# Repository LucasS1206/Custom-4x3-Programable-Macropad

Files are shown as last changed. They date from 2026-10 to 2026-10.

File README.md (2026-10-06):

# Custom 4x3 Macropad (with Rotary Encoder & OLED)
A custom 4x3 mechanical macropad I designed and built from scratch. This was designed for the intention of a dedicated keypad for a daily computer setup. I used this project as an opportunity to walk through the entire hardware development process from designing the circuit board in KiCad to writing the embedded C firmware in QMK.

## System Features
Layout: A 4x3 grid (12 keys) for custom shortcuts and macros.

Rotary Encoder: An EC11 clickable dial for master volume and media control.

Display: A 1.3" SH1106 OLED screen for real-time visual feedback.

Microcontroller: Pro Micro RP2040.

Firmware: Custom QMK integration, giving me complete control over every key switch, screen display, and dial action.

## Hardware Design (KiCad)
The hardware architecture and PCB were developed using KiCad 10.0:

Schematics: Built a 4x3 switch matrix with diodes to prevent key ghosting, alongside the specific pin routing for the encoder and microcontroller.

PCB Layout: Routed a compact, custom circuit board.

Iterative Design: During the layout phase, I caught and fixed an orientation error with the microcontroller footprint and adjusted the top-layer copper pour clearances to make sure the board would manufacture correctly without short-circuiting.

## QMK Firmware
The /firmware directory contains the configuration files (keymap.c, keyboard.json, config.h, and rules.mk) required to run the system.

## Repository Structure
/Hardware: The primary KiCad 10.0 design files (.kicad_pro, .kicad_sch, .kicad_pcb).

/firmware/testpad: The custom QMK configuration source files.

/Images: System documentation through images of all parts of the design proccess.

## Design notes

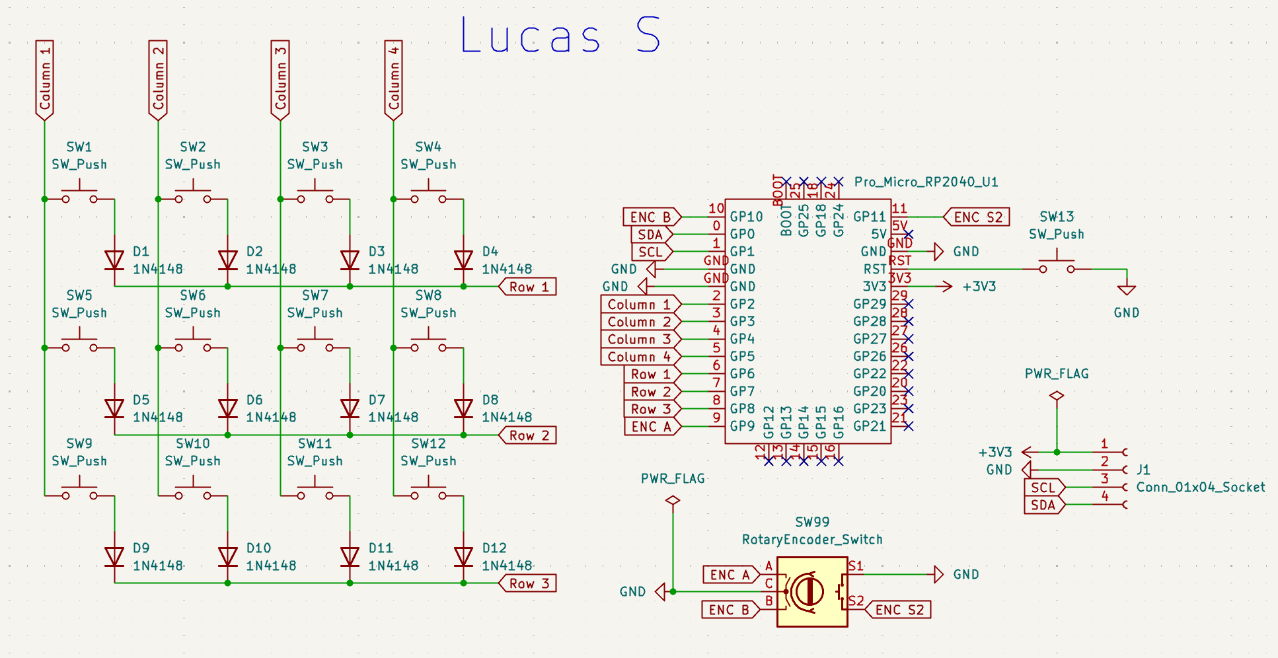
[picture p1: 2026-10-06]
Images/Schematic.png

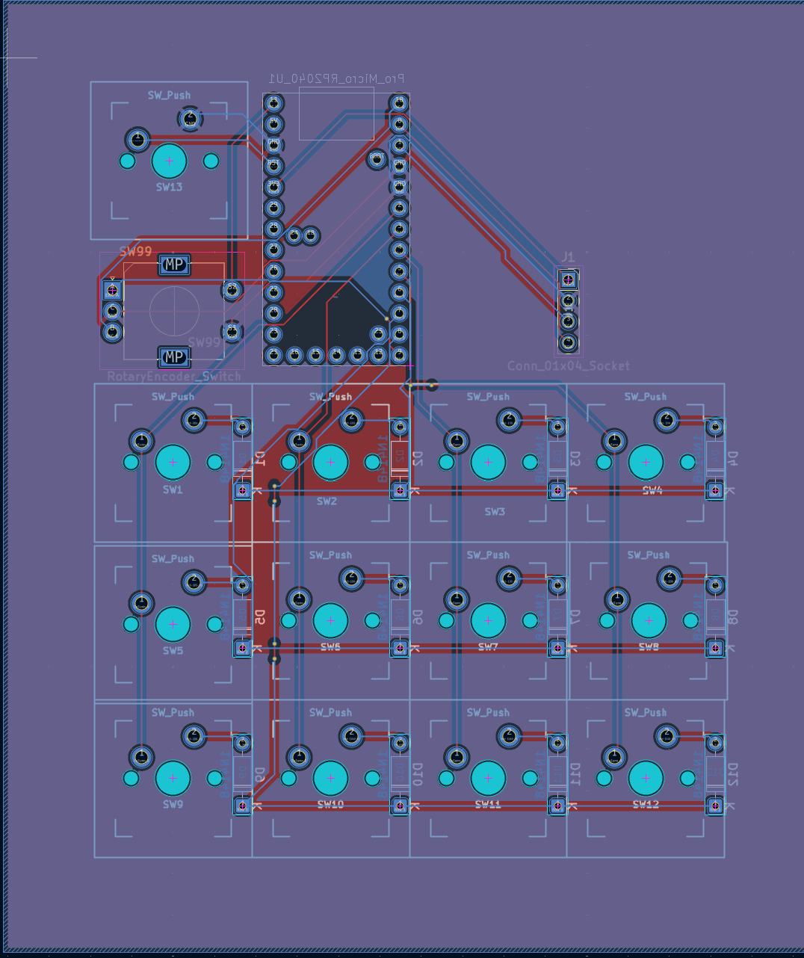
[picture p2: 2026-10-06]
Images/PCB Layout.png

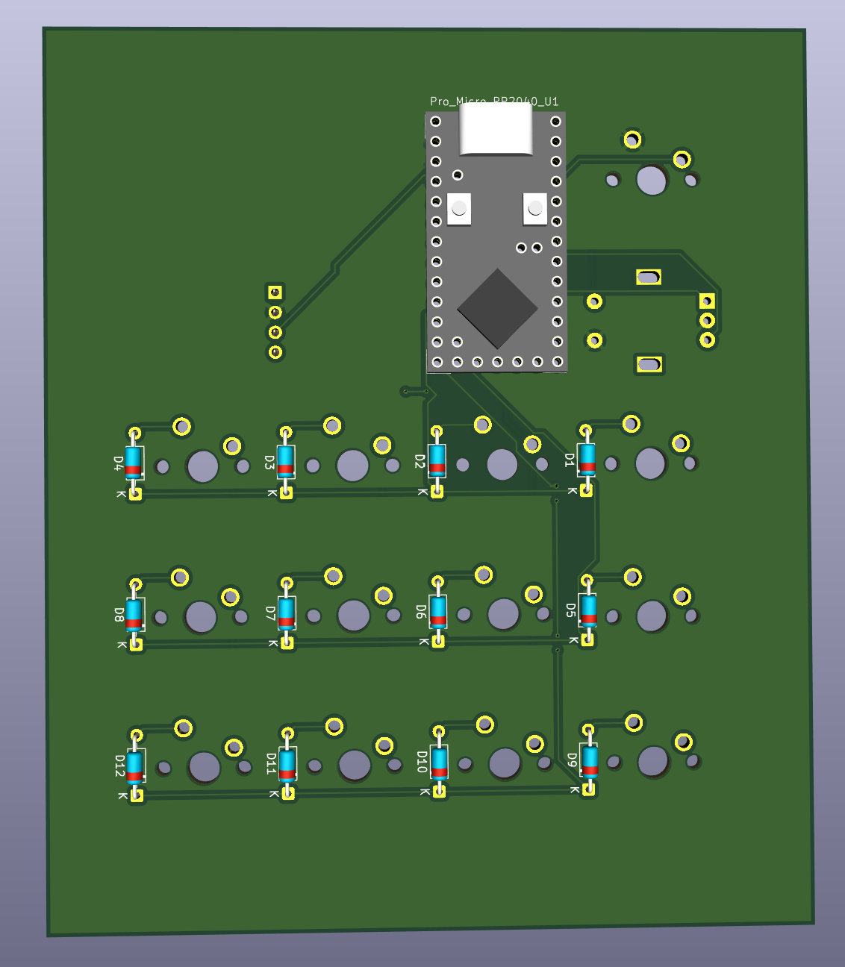
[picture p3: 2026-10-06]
Images/PCB 3D Model (Back).png

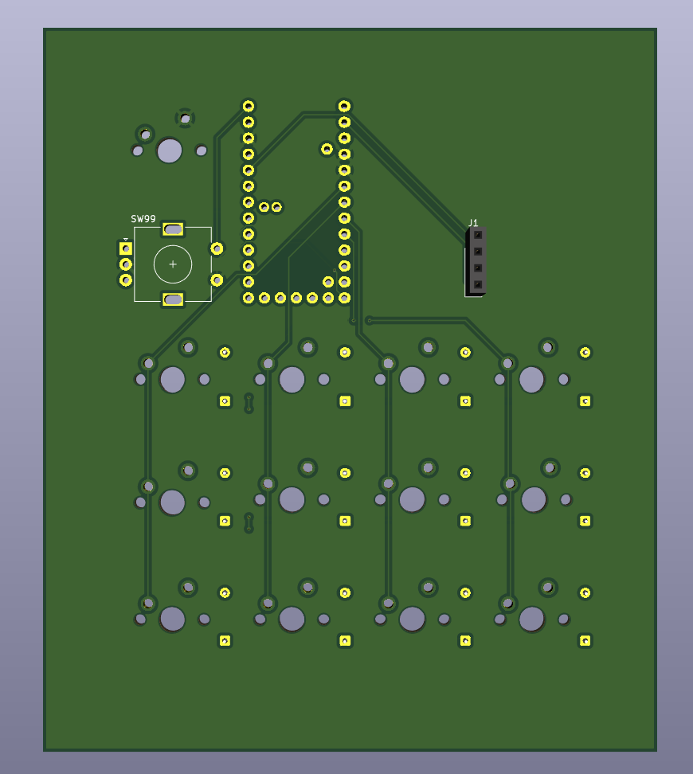
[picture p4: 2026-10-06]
Images/PCB 3D Model (Front).png

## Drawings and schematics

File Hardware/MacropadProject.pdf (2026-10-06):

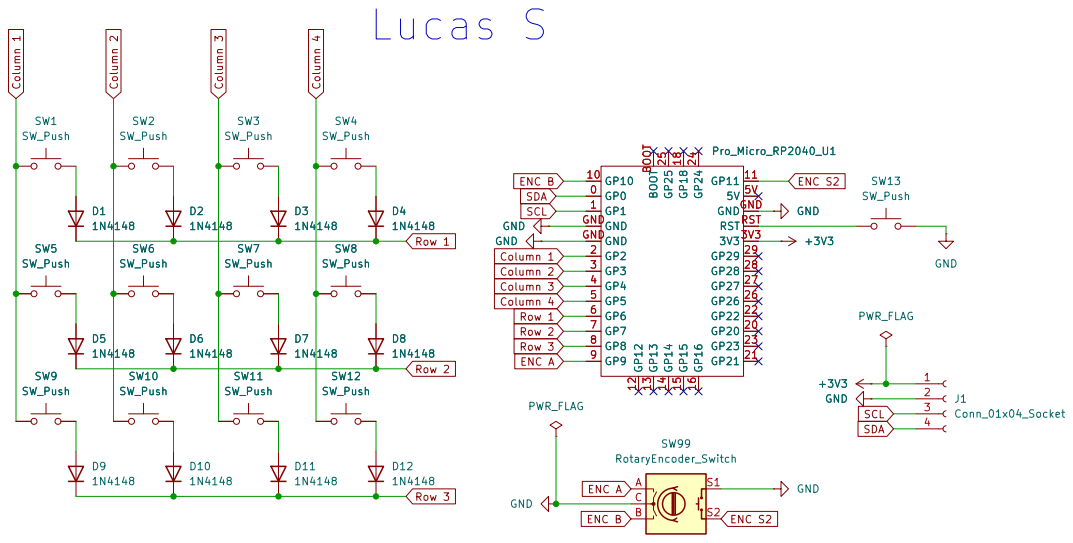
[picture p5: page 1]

SCL SDA Column 4 Column 2 Column 1 Row 1 Lucas S

Size: A4 | Rev:
KiCad E.D.A. 10.0.5 | Id: 1/1

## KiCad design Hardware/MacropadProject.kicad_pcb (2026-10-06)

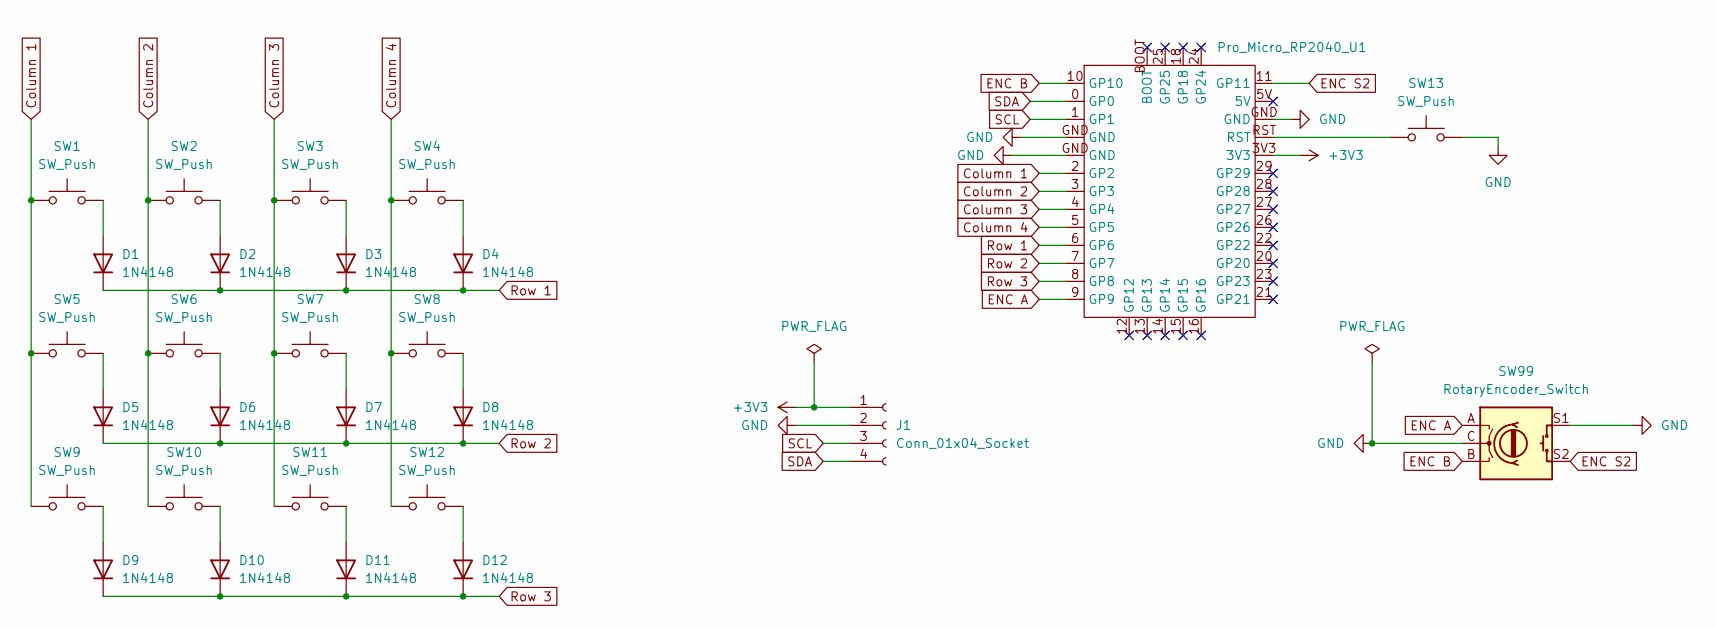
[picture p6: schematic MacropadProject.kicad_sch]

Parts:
D1, D2, D3, D4, D5, D6, D7, D8, D9, D10, D11, D12: 1N4148; D_DO-35_SOD27_P7.62mm_Horizontal
J1: Conn_01x04_Socket; PinSocket_1x04_P2.54mm_Vertical
Pro_Micro_RP2040_U1: pro_micro_rp2040
SW1, SW2, SW3, SW4, SW5, SW6, SW7, SW8, SW9, SW10, SW11, SW12, SW13: SW_Push; MX-Solderable-1U
SW99: RotaryEncoder_Switch; RotaryEncoder_Alps_EC11E-Switch_Vertical_H20mm

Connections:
+3V3: J1.1, Pro_Micro_RP2040_U1.3V3
Column 1: Pro_Micro_RP2040_U1.2 (GP2), SW1.1, SW5.1, SW9.1
Column 2: Pro_Micro_RP2040_U1.3 (GP3), SW2.1, SW6.1, SW10.1
Column 3: Pro_Micro_RP2040_U1.4 (GP4), SW3.1, SW7.1, SW11.1
Column 4: Pro_Micro_RP2040_U1.5 (GP5), SW4.1, SW8.1, SW12.1
ENC A: Pro_Micro_RP2040_U1.9 (GP9), SW99.A
ENC B: Pro_Micro_RP2040_U1.10 (GP10), SW99.B
ENC S2: Pro_Micro_RP2040_U1.11 (GP11), SW99.S2
GND: J1.2, Pro_Micro_RP2040_U1.GND, SW13.2, SW99.C, SW99.S1
unnamed: D1.2 (A), SW1.2
unnamed: D2.2 (A), SW2.2
unnamed: D3.2 (A), SW3.2
unnamed: D4.2 (A), SW4.2
unnamed: D5.2 (A), SW5.2
unnamed: D6.2 (A), SW6.2
unnamed: D7.2 (A), SW7.2
unnamed: D8.2 (A), SW8.2
unnamed: D9.2 (A), SW9.2
unnamed: D10.2 (A), SW10.2
unnamed: D11.2 (A), SW11.2
unnamed: D12.2 (A), SW12.2
unnamed: Pro_Micro_RP2040_U1.RST, SW13.1
Row 1: D1.1 (K), D2.1 (K), D3.1 (K), D4.1 (K), Pro_Micro_RP2040_U1.6 (GP6)
Row 2: D5.1 (K), D6.1 (K), D7.1 (K), D8.1 (K), Pro_Micro_RP2040_U1.7 (GP7)
Row 3: D9.1 (K), D10.1 (K), D11.1 (K), D12.1 (K), Pro_Micro_RP2040_U1.8 (GP8)
SCL: J1.3, Pro_Micro_RP2040_U1.1 (GP1)
SDA: J1.4, Pro_Micro_RP2040_U1.0 (GP0)

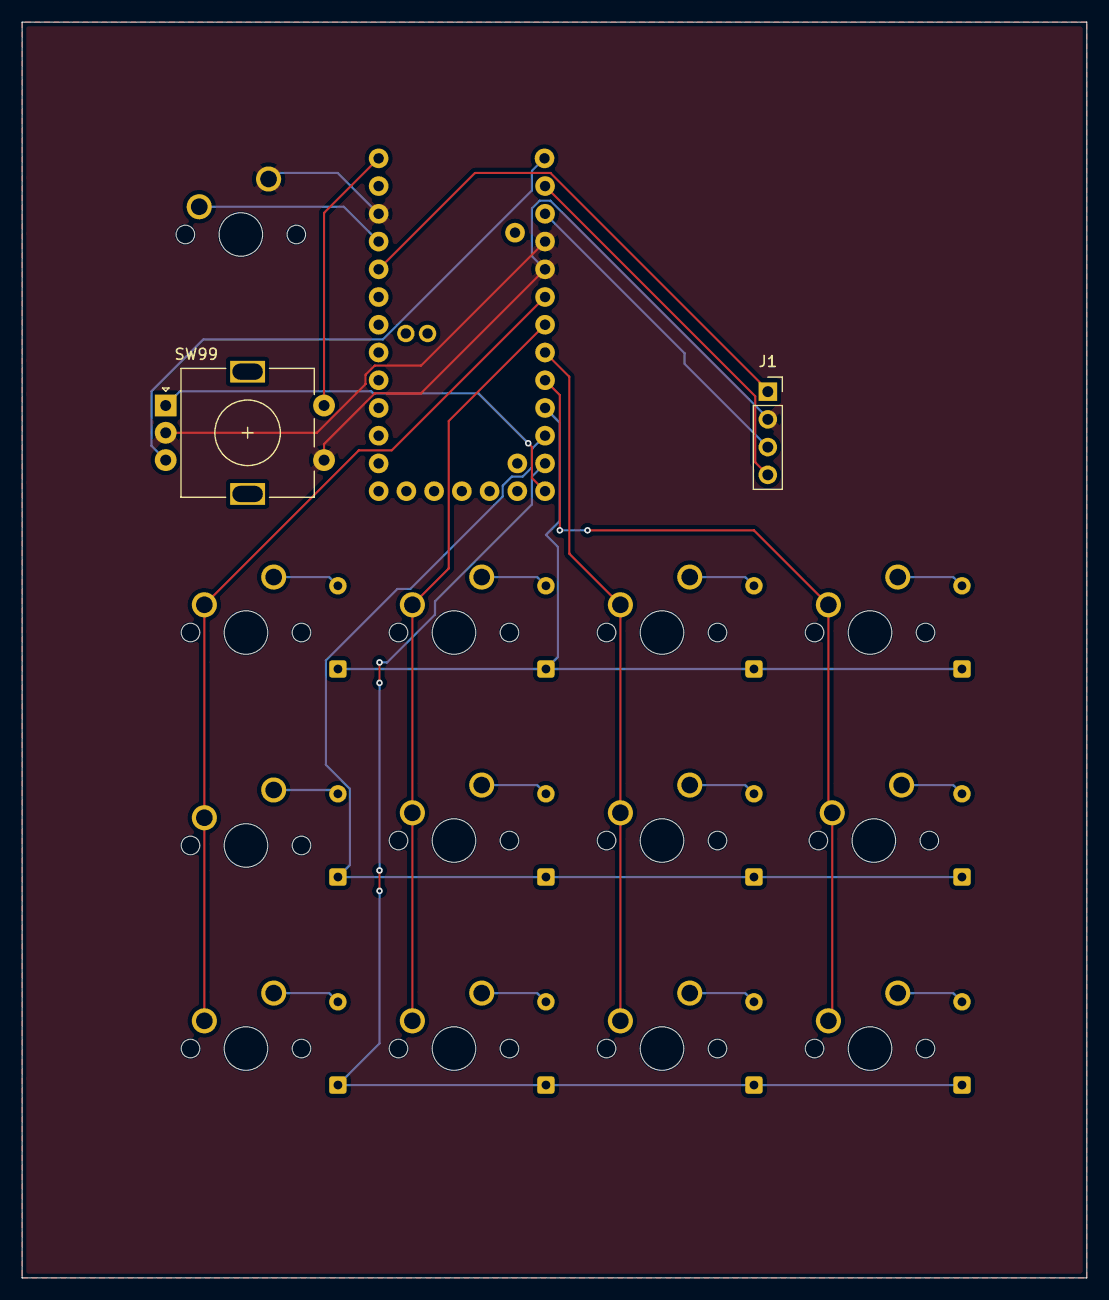
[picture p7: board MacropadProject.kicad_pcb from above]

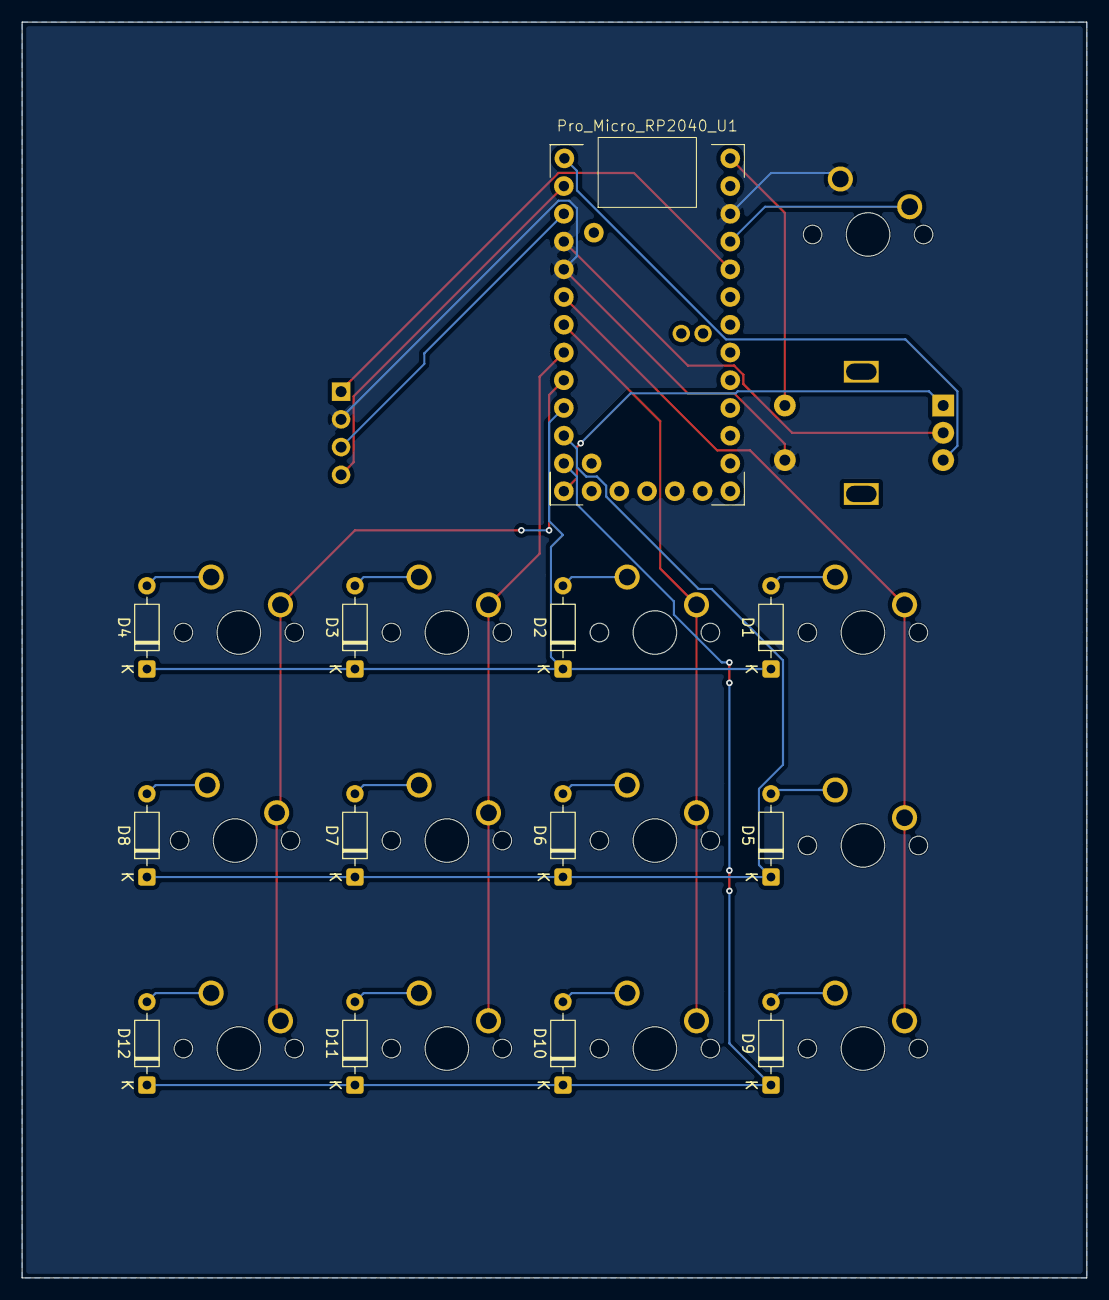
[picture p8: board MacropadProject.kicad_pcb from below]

Board: 2 copper layers, 97.5 x 115.0 mm, 28 parts (13 on the bottom side), 27 nets.

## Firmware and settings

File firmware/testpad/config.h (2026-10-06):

#pragma once


#undef I2C1_SDA_PIN
#undef I2C1_SCL_PIN


#define I2C_DRIVER I2CD1
#define I2C1_SDA_PIN GP0
#define I2C1_SCL_PIN GP1


#define ENCODER_RESOLUTION 4
#define DEBOUNCE 5

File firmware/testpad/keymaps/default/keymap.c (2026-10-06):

#include QMK_KEYBOARD_H


const uint16_t PROGMEM keymaps[][MATRIX_ROWS][MATRIX_COLS] = {
    [0] = LAYOUT(
        KC_7,    KC_8,    KC_9,    KC_VOLU,
        KC_4,    KC_5,    KC_6,    KC_VOLD,
        KC_1,    KC_2,    KC_3,    KC_MPLY
    )
};


#if defined(ENCODER_MAP_ENABLE)
const uint16_t PROGMEM encoder_map[][NUM_ENCODERS][NUM_DIRECTIONS] = {
    [0] = { ENCODER_CCW_CW(KC_MEDIA_PREV_TRACK, KC_MEDIA_NEXT_TRACK) }
};
#endif


void keyboard_post_init_user(void) {
    gpio_set_pin_input_high(GP11);
}


void matrix_scan_user(void) {
    static bool btn_pressed = false;
    static uint16_t btn_timer = 0;

    bool current_state = !gpio_read_pin(GP11);

    if (current_state != btn_pressed) {
        if (timer_elapsed(btn_timer) > 10) {
            btn_pressed = current_state;
            if (btn_pressed) {
                tap_code(KC_MUTE);
            }
            btn_timer = timer_read();
        }
    }
}


#ifdef OLED_ENABLE
bool oled_task_user(void) {
    oled_write_P(PSTR("4x3 Macropad\n"), false);
    oled_write_P(PSTR("RP2040 Active\n"), false);
    oled_write_P(PSTR("--------------\n"), false);

    uint8_t layer = get_highest_layer(layer_state);
    switch (layer) {
        case 0:
            oled_write_P(PSTR("Layer: Base\n"), false);
            break;
        default:
            oled_write_P(PSTR("Layer: Undef\n"), false);
            break;
    }
    return false;
}
#endif
